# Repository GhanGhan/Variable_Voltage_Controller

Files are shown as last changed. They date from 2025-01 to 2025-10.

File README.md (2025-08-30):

# Overview
Desktop device that outputs a variable voltage whos value is controlled by the user.  The user will be able to monitor the input and output voltage and current.  This device will be suitable for prototyping, lab-bench testing and recreational purposes.
**The firmware for this projected is in the "Program" folder.**
Adjusted
## Notable Features!!!!!!
- Reverse voltage protection
- Power multiplexing between the input voltage terminal block and input voltage jack (explanation of circuit in section Schematic->Power->System Power Input)
  - **Allows user to hot-swap power sources while minimzing conduction losses!!!!**
- Real time voltage and current updates
Labelled

## PCB Notes
- 6-Layer stackup: Signal/GNDD/VCC/PGND/AGND/Signal
- Manufactured by JLCPCB
PCB View

# System Architecture
The system provides:
- A jack and terminal block for connecting to an external power supply with a range of 3-17V
- A screen to display the input voltage, input current, output voltage and output current in real time
- The ability to change the output voltage from 1.3V to 20V
- Terminal block connectors that allow an external load to connect to this device
Block Diagram

## System Description
An external power supply connects to the device via the input connectors.  The voltage is stepped down to 3.3V to power the display, microcontroller, and voltage controller.  A voltage and current sensor measures the external power supply’s voltage and current output and sends the readings to the microcontroller.  The user can operate the voltage controller to adjust the voltage sent to the output connector, which involves either a buck or boost conversion as the output voltage can range from 0 to 20V.  Another set of voltage and current sensors measures the voltage and current delivered to the load and sends those readings to the microcontroller.  The microcontroller processes the signals received from the sensors and sends the processed data to the display, allowing the user to view the voltage and current supplied by the external power supply as well as the voltage and current delivered to the load.

# Schematics
## Power 
Power

### System Power Input
- Power source connects to the device via a jack or a screw terminal block
- Systems needs at least 3V, and input voltage should not exceed 17V
-	Power Multiplexer circuit acts like an OR-GATE, automatically allows the higher input voltage to power the device
-	For more information about the circuit operation: [Basics of Ideal Diodes](https://www.ti.com/lit/an/slvae51a/slvae51a.pdf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)
-	Supplies power to the 3.3V buck converter and the buck-boost converter
### 3V3 Priority Power Multiplexing
-	Either the 3.3V buck converter or the 3.3V pin from the ST-Link programmer interface can be used to power the 3.3V circuitry
-	Priority is given to the buck converter
-	For more information about the circuit operation: [Basics of Power MUX](https://www.ti.com/lit/an/slvae51a/slvae51a.pdf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)
### Variable Power Output
-	Can deliver between 1.32V to 20V and up to 4A current
-	Maximum output power for each voltage given by: $P_O = \frac{5}{3}V_I + 10$
-	Potentiometer in the feedback circuitry allows the user to control the output voltage
### 3V LDO - Display Power
-	LDO used to power the LCD screen, as the nominal input voltage is 3V
### Power-On Indicator
- Indicates whether the system is receiving power

## Microcontroller
Microcontroller

-	Powered by 3.3V and uses a 16MHz clock
-	Can be programmed/debugged via the SWD interface
- Senses the input current and voltage as well as the output current and voltage via the ADC pins
- Communicates with the LCD display via the SPI interface

## Sensors
Sensors

### Current Sensors
- Composed of an 11 mΩ current-shunt resistor (shown in **Power Schematic**) and a difference amplifier with a 50V/V gain
- Senses uni-directional current up to 4A, scales output to 3.3V 
### Voltage Sensors
- Made using a voltage divider circuit
- Appropriately scaled so that the max voltage it experiences will output to 3.3V approximately

## Display
LCD

-	Powered by 3.0V
-	Has a backlight that is always on
-	Receives information about the system from the microcontroller via SPI 
- Display has a refresh rate of 10Hz

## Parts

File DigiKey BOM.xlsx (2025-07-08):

Reference | Value | Datasheet | Footprint | Qty | Manufacturer Part # | Cost | Total Cost
J102,J103 | Screw_Terminal_01x02 | ~ | TerminalBlock_Phoenix:TerminalBlock_Phoenix_MKDS-1,5-2_1x02_P5.00mm_Horizontal | 2 | 1984617 | $1.26 | $2.52
J201 | Conn_01x05 | ~ | Connector_PinHeader_2.54mm:PinHeader_1x05_P2.54mm_Vertical | 1 | PPTC051LFBN-RC | $0.62 | $0.62
RV101 | 1M ADJ | ~ | Potentiometer_THT:Potentiometer_Bourns_PTV09A-1_Single_Vertical | 1 | PTV09A-4025F-A105 | $1.31 | $1.31
U301 | NHD-C12832A1Z-FSW-FBW-3V3 |  | Display:NHD-C12832A1Z-FSRGB | 1 | NHD-C12832A1Z-FSW-FBW-3V3 | $20.04 | $20.04
C122,C123,C302,C303,C304,C305,C306 | 1uF | ~ | Capacitor_SMD:C_0402_1005Metric | 7 | CL05A105KP5NNNC | $0.15 | $1.05
D201,D202,D203,D204 | D_TVS | ~ | Diode_SMD:D_SOD-323 | 4 | PESD3V3L1BA,115 | $0.43 | $1.72
U104 | TPS62172DSG | http://www.ti.com/lit/ds/symlink/tps62170.pdf | Package_SON:WSON-8-1EP_2x2mm_P0.5mm_EP0.9x1.6mm_ThermalVias | 1 | TPS62172DSGR | $1.83 | $1.83
R101,R104,R105,R107,R108,R109,R110,R115 | 100k | ~ | Resistor_SMD:R_0402_1005Metric | 8 | RC0402FR-07100KL | $0.16 | $1.28
U106 | MCP1700T-3002E/TT | http://ww1.microchip.com/downloads/en/DeviceDoc/20001826D.pdf | Package_TO_SOT_SMD:SOT-23 | 1 | MCP1700T-3002E/TT | $0.80 | $0.80
C301,C307,C308 | 2.2uF | ~ | Capacitor_SMD:C_0402_1005Metric | 3 | GRM155R61E225ME15D | $0.28 | $0.84
C201 | 4.7uF | ~ | Capacitor_SMD:C_0402_1005Metric | 1 | GRM155R60J475KE96D |  | $0.00 | Not in Digikey
C121 | 10nF | ~ | Capacitor_SMD:C_0402_1005Metric | 1 | GRM155R71E103KA01D | $0.15 | $0.15
C101,C102,C111 | 22uF | ~ | Capacitor_SMD:C_1206_3216Metric | 3 | GRM31CR61E226KE15L |  | $0.00 | Obselete
U101 | MCP6541T-I/OT | http://ww1.microchip.com/downloads/en/DeviceDoc/MCP6561-1R-1U-2-4-1.8V-Low-Power-Push-Pull-Output-Comparator-DS20002139E.pdf | Package_TO_SOT_SMD:SOT-353_SC-70-5 | 1 | MCP6541T-I/OT | $0.61 | $0.61
C108,C109,C110,C112,C113,C115 | 10uF | ~ | Capacitor_SMD:C_0805_2012Metric | 6 | GRM21BR61E106KA73L | $0.35 | $2.10
R401 | 9.1k | ~ | Resistor_SMD:R_0603_1608Metric | 1 | RC0603FR-079K1L | $0.16 | $0.16
R402 | 2.2k | ~ | Resistor_SMD:R_0603_1608Metric | 1 | RC0603FR-072K2L | $0.16 | $0.16
D103,D104,D105 | BAT54WS-7-F | https://assets.nexperia.com/documents/data-sheet/BAT54J.pdf | Diode_SMD:D_SOD-323F | 3 | BAT54WS-7-F | $0.15 | $0.45
U401,U402 | INA213AIDCKR |  | Package_TO_SOT_SMD:SOT-363_SC-70-6 | 2 | INA213AIDCKR | $1.22 | $2.44
Q102,Q103 | IRFML8244TRPBF | https://ngspice.sourceforge.io/docs/ngspice-html-manual/manual.xhtml#cha_MOSFETs | Package_TO_SOT_SMD:SOT-23 | 2 | IRFML8244TRPBF | $0.56 | $1.12
C103,C104,C105,C106,C107,C114,C116,C117,C118,C202,C205,C401,C402 | 0.1uF | ~ | Capacitor_SMD:C_0402_1005Metric | 13 | CL05B104KA5NNNC | $0.12 | $1.56
C120 | 100uF | ~ | Capacitor_SMD:CP_Elec_6.3x7.7 | 1 | EEEFTH101XAP | $1.37 | $1.37
R102,R103 | 50k | ~ | Resistor_SMD:R_0402_1005Metric | 2 | RTT025002FTH |  | $0.00
R114 | 140k | ~ | Resistor_SMD:R_0603_1608Metric | 1 | RC0603FR-07140KL | $0.16 | $0.16
C119 | 240pF | ~ | Capacitor_SMD:C_0603_1608Metric | 1 | GRM1885C1H241JA01D | $0.21 | $0.21
Y201 | 16MHz | ~ | Crystal:Crystal_SMD_3225-4Pin_3.2x2.5mm | 1 | 7U16000E12UCG |  | $0.00
Q104,Q105,Q106,Q107 | AO3407 | http://www.aosmd.com/pdfs/datasheet/AO3401A.pdf | Package_TO_SOT_SMD:SOT-23 | 4 | AO3407 |  | $0.00
R404 | 4.7K | ~ | Resistor_SMD:R_0402_1005Metric | 1 | ERJ2RKF4701X | $0.16 | $0.16
L101,L102 | 2.2uH | ~ | Inductor_SMD:L_Sunlord_MWSA0503S | 2 | MWSA0503S-2R2MT | $1.21 | $2.42
R403 | 24K | ~ | Resistor_SMD:R_0402_1005Metric | 1 | ERJ2RKF2402X | $0.16 | $0.16
R113 | 160R | ~ | Resistor_SMD:R_0603_1608Metric | 1 | ERJ2RKF1600X | $0.16 | $0.16
R106,R116 | 11mR | ~ | Resistor_SMD:R_1210_3225Metric | 2 | 1210W2F110MT5E |  | $0.00
C203,C204 | 14pF | ~ | Capacitor_SMD:C_0402_1005Metric | 2 | 0402N140J500CT |  | $0.00
Q101,Q108,Q109,Q110 | AO3416 | http://www.aosmd.com/pdfs/datasheet/AO3400A.pdf | Package_TO_SOT_SMD:SOT-23 | 4 | AO3416 | $0.74 | $2.96
D101,D102 | D_TVS | ~ | Diode_SMD:D_SOD-882 | 2 | PESD18VF1BLYL | $0.25 | $0.50
U201 | STM32G030F6Px | https://www.st.com/resource/en/datasheet/stm32g030f6.pdf | Package_SO:TSSOP-20_4.4x6.5mm_P0.65mm | 1 | STM32G030F6P6 | $2.02 | $2.02
R112 | 4.3k | ~ | Resistor_SMD:R_0805_2012Metric | 1 | RT0805BRD074K3L | $0.25 | $0.25
R111 | 5k | ~ | Resistor_SMD:R_0603_1608Metric | 1 | RT0603BRE075KL | $0.27 | $0.27
SW201 | SW_Push | ~ | Button_Switch_SMD:SW_Tactile_SPST_NO_Straight_CK_PTS636Sx25SMTRLFS | 1 | PTS636SK25SMTRLFS | $0.34 | $0.34
J101 | Jack-DC | ~ | Connector_BarrelJack:BarrelJack_CUI_PJ-063AH_Horizontal | 1 | PJ-063AH |  | $0.00
U102,U103 | LM74700 | http://www.ti.com/lit/gpn/LM74700-Q1 | Package_TO_SOT_SMD:SOT-23-6 | 2 | LM74700QDBVRQ1 | $2.62 | $5.24
R117 | 6.4k | ~ | Resistor_SMD:R_0603_1608Metric | 1 | ARG03DTC6401N |  | $0.00
D106 | Green LED | ~ | LED_SMD:LED_0603_1608Metric | 1 | 150060GS75000 | $0.24 | $0.24
U105 | TPS552872RYQR |  | Buck_Boost:21-PowerVFQFN | 1 | TPS552872RYQR | $6.63 | $6.63
Total |  |  |  | 98 |  |  | $63.85

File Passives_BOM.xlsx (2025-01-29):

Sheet: Capacitors
Capacitance (uF) | Name | Tolerance % | Voltage Rating (V) | Size | Caps
1uF | CL05A105KP5NNNC (https://jlcpcb.com/partdetail/15107-CL05A105KP5NNNC/C14445) | 10 | 10 | 0402 | C122, C123, C302-C306
22uF | GRM31CR61E226KE15L (https://jlcpcb.com/partdetail/MurataElectronics-GRM31CR61E226KE15L/C77091) | 10 | 25 | 1206 | C101, C102, C111
0.1uF | CL05B104KA5NNNC (https://jlcpcb.com/partdetail/166764-CL05B104KA5NNNC/C155422) | 10 | 25 | 0402 | C103-C107, C114, C116, C117, C118, C202, C205, C401, C402
10uF | GRM21BR61E106KA73L (https://jlcpcb.com/partdetail/MurataElectronics-GRM21BR61E106KA73L/C84416) | 10 | 25 | 0805 | C108, C109, C110, C112, C113, C115
2.2uF | GRM155R61E225ME15D (https://jlcpcb.com/partdetail/MurataElectronics-GRM155R61E225ME15D/C72203) | 20 | 25 | 0402 | C301, C307, C308
14pF | 0402N140J500CT (https://jlcpcb.com/partdetail/Walsin_TechCorp-0402N140J500CT/C458857) | 5 | 50 | 0402 | C203, C204
240pF | GRM1885C1H241JA01D (https://jlcpcb.com/partdetail/196998-GRM1885C1H241JA01D/C185593) | 5 | 50 | 0603 | C119
100uF | EEEFTH101XAP (https://jlcpcb.com/partdetail/Panasonic-EEEFTH101XAP/C165974) | 20 | 50 | D6.3xL7.7mm | C120
10nF | GRM155R71E103KA01D (https://jlcpcb.com/partdetail/MurataElectronics-GRM155R71E103KA01D/C77013) | 10 | 25 | 0402 | C121
4.7uF | GRM155R60J475KE96D (https://jlcpcb.com/partdetail/MurataElectronics-GRM155R60J475KE96D/C76995) | 10 | 6.3 | 0402 | C201

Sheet: Inductor
Inductance | Name | Tolerance % | Saturation Current (A) | Size | Inductors
2.2uH | MWSA0503S-2R2MT | 20% | 7.2 | 5.4x5.2x2.8mm | L101, L102

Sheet: Resistors
Resistance | Name | Tolerance % | Power | Size | Resistors
100kohm | RC0402FR-07100KL (https://jlcpcb.com/partdetail/Yageo-RC0402FR07100KL/C60491) | 1 | 62.5mW | 0402 | R101, R104, R105, R107-R110, R115
50kohm | RTT025002FTH (https://jlcpcb.com/partdetail/Ralec-RTT025002FTH/C166559) | 1 | 62.5mW | 0402 | R102, R103
11mohm | 1210W2F110MT5E (https://jlcpcb.com/partdetail/415373-1210W2F110MT5E/C422423) | 1 | 500mW | 1210 | R106, R116
5kohm | RT0603BRE075KL (https://jlcpcb.com/partdetail/Yageo-RT0603BRE075KL/C862232) | 0.1 | 100mW | 0603 | R111
4.3kohm | RT0805BRD074K3L (https://jlcpcb.com/partdetail/Yageo-RT0805BRD074K3L/C728653) | 0.1 | 125mW | 0805 | R112
160ohm | ERJ2RKF1600X (https://jlcpcb.com/partdetail/Panasonic-ERJ2RKF1600X/C413068) | 1 | 100mW | 0402 | R113
140kohm | RC0603FR-07140KL (https://jlcpcb.com/partdetail/Yageo-RC0603FR07140KL/C185372) | 1 | 100mW | 0603 | R114
6.4kohm | ARG03DTC6401N (https://jlcpcb.com/partdetail/VikingTech-ARG03DTC6401N/C3014413) | 0.5 | 100mW | 0603 | R117
9.1kohm | RC0603FR-079K1L (https://jlcpcb.com/partdetail/Yageo-RC0603FR079K1L/C114639) | 1 | 100mW | 0603 | R401
2.2kohm | RC0603FR-072K2L (https://jlcpcb.com/partdetail/Yageo-RC0603FR072K2L/C114662) | 1 | 100mW | 0603 | R402
24kohm | ERJ2RKF2402X (https://jlcpcb.com/partdetail/Panasonic-ERJ2RKF2402X/C409902) | 1 | 100mW | 0402 | R403
4.7kohm | ERJ2RKF4701X (https://jlcpcb.com/partdetail/Panasonic-ERJ2RKF4701X/C400631) | 1 | 100mW | 0402 | R404

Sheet: Potentiometer
Resistance | Name | Tolerance % | Power | Size | Resistors
1Mohm | PTV09A-4025F-A105 (https://www.digikey.ca/en/products/detail/bourns-inc/PTV09A-4025F-A105/3820576) | 20 | 50mW | Through Hole, Snap In | Rv101

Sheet: Switch
Name | Size | Switch
PTS636SK25SMTRLFS (https://jlcpcb.com/partdetail/ck-PTS636SK25SMTRLFS/C2689642) | 6x3.5 | SW201

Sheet: Connectors
Connector | Name | Voltage Rating | Current Rating | Size (pitch) | Annotation
Input Voltage Jack | PJ-063AH (https://www.digikey.ca/en/products/detail/same-sky-formerly-cui-devices/PJ-063AH/2161208) | 24V | 8A | 5.5mm | J101
Input Voltage Block | 1984617 (https://www.digikey.ca/en/products/detail/phoenix-contact/1984617/950849) | 300V | 10A | 3.5mm | J102
Output Voltage Block | 1984617 (https://www.digikey.ca/en/products/detail/phoenix-contact/1984617/950849) | 300V | 10A | 3.5mm | J103
ST-Link Header | PPTC051LFBN-RC (https://www.digikey.ca/en/products/detail/sullins-connector-solutions/PPTC051LFBN-RC/807239) | 250V | 3A | 2.54mm | J201

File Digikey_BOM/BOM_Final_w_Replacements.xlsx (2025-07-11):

Index | Quantity | Part Number | Manufacturer Part Number | Description | Customer Reference | Available | Backorder | Unit Price | Extended Price USD
1 | 1 | CP-063AH-ND | PJ-063AH | CONN PWR JACK 2X5.5MM SOLDER | J101 | 1 | 0 | 1.5 | 1.50
2 | 2 | 277-1721-ND | 1984617 | TERM BLK 2POS SIDE ENT 3.5MM PCB | J102,J103 | 2 | 0 | 0.86 | 1.72
3 | 1 | S6103-ND | PPTC051LFBN-RC | CONN HDR 5POS 0.1 TIN PCB | J201 | 1 | 0 | 0.38 | 0.38
4 | 1 | 118-PTV09A-4025F-A105-ND | PTV09A-4025F-A105 | POT 1M OHM 1/20W CARBON LOG | RV101 | 1 | 0 | 0.89 | 0.89
5 | 1 | NHD-C12832A1Z-FSW-FBW-3V3-ND | NHD-C12832A1Z-FSW-FBW-3V3 | GRAPHIC DISPLAY FSTN BLACK (WHIT | U301 | 1 | 0 | 12.78 | 12.78
6 | 13 | 1276-6720-1-ND | CL05B104KA5NNNC | CAP CER 0.1UF 25V X7R 0402 | C103,C104,C105,C106,C107,C114,C116,C117,C118,C20 | 13 | 0 | 0.008 | 0.10
7 | 1 | 490-1436-1-ND | GRM1885C1H241JA01D | CAP CER 240PF 50V C0G/NP0 0603 | C119 | 1 | 0 | 0.14 | 0.14
8 | 1 | PCE5024CT-ND | EEE-FTH101XAP | CAP ALUM 100UF 20% 50V SMD | C120 | 1 | 0 | 0.93 | 0.93
9 | 3 | BAT54WS-FDICT-ND | BAT54WS-7-F | DIODE SCHOTTKY 30V 100MA SOD323 | D103,D104,D105 | 3 | 0 | 0.1 | 0.30
10 | 2 | 490-GCM1555C1H110FA16DCT-ND | GCM1555C1H110FA16D | CAP CER 11PF 50V C0G/NP0 0402 | C203,C204 | 2 | 0 | 0.1 | 0.20
11 | 1 | 732-4971-1-ND | 150060GS75000 | LED GREEN CLEAR 0603 SMD | D106 | 1 | 0 | 0.15 | 0.15
12 | 1 | P160LCT-ND | ERJ-2RKF1600X | RES SMD 160 OHM 1% 1/10W 0402 | R113 | 1 | 0 | 0.1 | 0.10
13 | 1 | P24.0KLCT-ND | ERJ-2RKF2402X | RES SMD 24K OHM 1% 1/10W 0402 | R403 | 1 | 0 | 0.1 | 0.10
14 | 1 | MCP6541T-I/OTCT-ND | MCP6541T-I/OT | IC COMPARATOR 1 GEN PUR SOT23-5 | U101 | 1 | 0 | 0.39 | 0.39
15 | 1 | MCP1700T-3002E/TTCT-ND | MCP1700T-3002E/TT | IC REG LINEAR 3V 250MA SOT23-3 | U106 | 1 | 0 | 0.51 | 0.51
16 | 2 | 296-53420-1-ND | LM74700QDBVTQ1 | LOW IQ, IDEAL DIODE CONTROLLER | U102,U103 | 2 | 0 | 2.07 | 4.14
17 | 1 | 311-140KHRCT-ND | RC0603FR-07140KL | RES 140K OHM 1% 1/10W 0603 | R114 | 1 | 0 | 0.1 | 0.10
18 | 2 | 1727-1480-1-ND | PESD18VF1BLYL | TVS DIODE 18VWM 17VC DFN1006-2 | D101,D102 | 2 | 0 | 0.17 | 0.34
19 | 4 | 1727-3825-1-ND | PESD3V3L1BA,115 | TVS DIODE 3.3VWM 26VC SOD323 | D201,D202,D203,D204 | 4 | 0 | 0.29 | 1.16
20 | 4 | 785-1011-1-ND | AO3416 | MOSFET N-CH 20V 6.5A SOT23-3L | Q101,Q108,Q109,Q110 | 4 | 0 | 0.5 | 2.00
21 | 2 | IRFML8244TRPBFCT-ND | IRFML8244TRPBF | MOSFET N-CH 25V 5.8A SOT23 | Q102,Q103 | 2 | 0 | 0.36 | 0.72
22 | 1 | CKN12324-1-ND | PTS636SKG25SMTR LFS | SWITCH TACTILE SPST-NO 0.05A 12V | SW201 | 1 | 0 | 0.24 | 0.24
23 | 2 | 296-26072-1-ND | INA213AIDCKR | IC CURR SENSE 1 CIRCUIT SC70-6 | U401,U402 | 2 | 0 | 0.77 | 1.54
24 | 4 | 785-AOSS21311CCT-ND | AOSS21311C | MOSFET P-CH 30V 4.3A SOT23-3 | Q104,Q105,Q106,Q107 | 4 | 0 | 0.46 | 1.84
25 | 2 | 541-CRCW040250K0FKEDCT-ND | CRCW040250K0FKED | D10/CRCW0402 100 50K 1% ET7 E3 | R102,R103 | 2 | 0 | 0.1 | 0.20
26 | 2 | 1712-RLC73PV2ER011FTDCT-ND | RLC73PV2ER011FTD | RLC73PV 2E R011 1% 5K RL | R106,R116 | 2 | 0 | 0.84 | 1.68
27 | 1 | RMCF0805FT4K30CT-ND | RMCF0805FT4K30 | RES 4.3K OHM 1% 1/8W 0805 | R112 | 1 | 0 | 0.1 | 0.10
28 | 1 | 2019-RN73R1JTTD6421B25CT-ND | RN73R1JTTD6421B25 | RES 6.42K OHM 0.1% 1/10W 0603 | R117 | 1 | 0 | 0.12 | 0.12
29 | 1 | 2019-RK73H1ERTTP4751FCT-ND | RK73H1ERTTP4751F | RES 4.75K OHM 1% 1/10W 0402 | R404 | 1 | 0 | 0.13 | 0.13
30 | 1 | 541-MCT06030D5001BP500CT-ND | MCT06030D5001BP500 | RES 5K OHM 0.1% 1/10W 0603 | R111 | 1 | 0 | 0.19 | 0.19

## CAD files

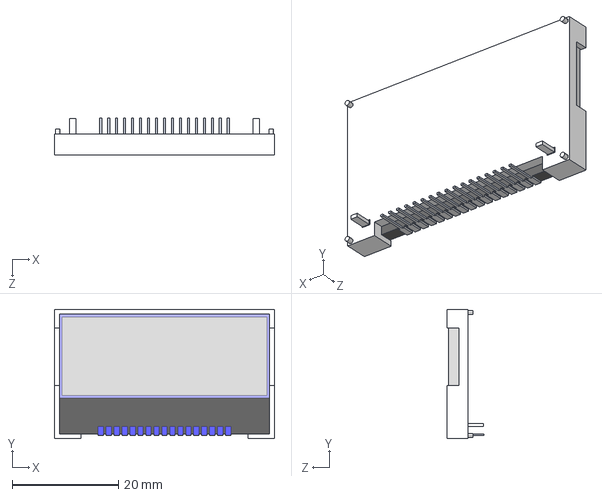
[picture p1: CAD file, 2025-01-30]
Var_Volt_Conv/Project_Library/3d_Models/NHD-C12832A1Z.STEP
41.4 x 24.3 x 7.00 mm

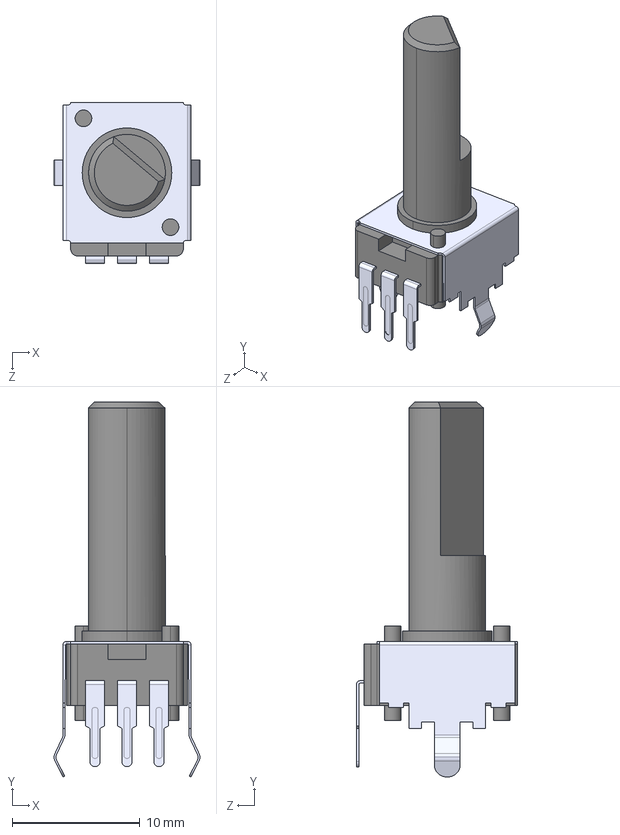
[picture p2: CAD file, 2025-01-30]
Var_Volt_Conv/Project_Library/3d_Models/PTV09A-4225F-B104.step
11.4 x 29.3 x 12.6 mm

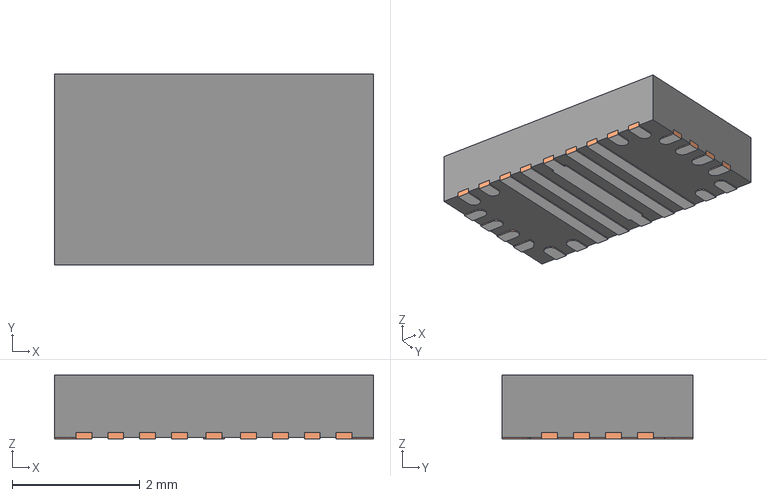
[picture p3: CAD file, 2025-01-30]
Var_Volt_Conv/Project_Library/3d_Models/RYQ0021A.stp
5.00 x 3.00 x 1.00 mm
BODY-QFN
FRAME-RYQ0021A

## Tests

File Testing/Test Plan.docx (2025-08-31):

# Variable Voltage Controller Test Plan

# Tools Required

- Benchtop power supply that can output up to 17V and 5A
- Digital multimeter that can perform continuity checks and measure up to 20V
- A variable power supply that can connect to a DC power jack
- The STM32CubeIDE that can run the program on the microcontroller in Debug Mode
- Digital oscilloscope
- Variable resistor and or rheostat

# Bring-Up

## Visual Inspection & Continuity Check

- Ensure all components are soldered onto the board and in the correct orientation
- Verify that there are no shorts between the power traces (Vin, Vo, 3.3V, 3.0V) and ground

## Power On

- Ensure that the output voltage terminal is in an open-circuit state
- Connect terminal block to bench-top power supply
- Turn bench top power supply on and slowly increase the voltage to 5V
- Check that the power indicator LED is on and that none of the components are heating up
- Use multimeter to check that all non-varying power rails (Vin, 3.3V and 3.0V) are at the correct value
- Increase input voltage from 5V to 17V (maximum input voltage for the device), recheck that none of the components overheating and that all the non-varying power rails are still set to the correct voltage level
- Connect a multimeter to the output terminal
- Rotate the potentiometer from it’s lowest setting to it’s highest setting, check that the output voltage increases from 1.32V to 20V

## Firmware Validation

- Connect device to a computer via the SWD interface, check that the computer can identify the microcontroller
- Upload a program that allows the microcontroller to transmit data to the LCD screen via the SPI interface, check that the message is correct
- Write and upload a program that the device will use during normal operation

# Functional Testing

## System Input Voltage Multiplexer Test

- Purpose: To confirm that the power multiplexer allows for two voltage sources to connect to the PCB at the same time, and the source with the larger voltage will deliver power to the device
- Procedure:
  - Ensure no load is connected to the output voltage terminals
  - Connect a variable power source to the DC power jack
  - Connect the bench-top supply source to the terminal block
  - A) Set the power jack source to 9V, vary the terminal block source from 3V to 17V
  - B) Set the terminal block source to 9V, vary the jack source from 3V to 17V
- Expected Result:
  - The power indicator LED and LCD screen should be turned on for the duration of the test
  - A – while the jack source is set to 9V, the LCD screen should display an input voltage of 9V until the benchtop supply > 9V, after which the measured input voltage should equal the benchtop supply source
  - B – while the terminal source is set to 9V, the LCD screen should display an input voltage of 9V until the jack source is > 9V, after which the measured input voltage should equal the jack supply source

## DC-DC Conversion Test

- Purpose: To confirm that the input voltage is accurately sensed by the input voltage sensor and that the value is displayed on the LCD screen error free
- Procedure:
  - Ensure no load is connected to the output voltage terminal
  - Connect the benchtop power supply to the input terminal block
  - Connect the oscilloscope probes to the input and output terminal blocks
  - Connect the programmer to the board, and operate the device in debug mode
    - Place a breakpoint after all the electrical value print statements
  - Change output voltage to Vo = {1.32V, 4V, 10V, 20V}
    - Change input voltage Vi = {3V, 6V, 12V, 17V
      - Set resistor value so that output current will be 4mA, 400mA, 1.5A and 4A/Max value
      - Record Vo, Vi, Io and Ii
      - Record oscilloscope waveform of Vo and Vi
      - ***If output value is ‘unstable’, make note of it
- Expected Result
  - Electrical values are stable under various loads
  - Power output limited by P = 1.667V + 10

## 3.3V Priority Multiplexer Test

- Purpose: To confirm that the programming header supplies the 3.3V circuitry with power if no supply is connected to the input terminals, otherwise the buck converter supplies the PCB with 3.3V
- Procedure:
  - Connect the benchtop power supply to the input terminal block and turn it on
  - Connect the programming header to the PCB and the laptop
  - Turn the power supply off, check the power indicator light of the PCB
  - Disconnect both the programming header and the power supply, then reconnect both and turn on the power supply
  - Unplug the programming header, check the power indicator light of the PCB
- Expected Result:
  - If both the header and benchtop supply are connected at the same time, the power indicator light should remain on if either of them are unplugged

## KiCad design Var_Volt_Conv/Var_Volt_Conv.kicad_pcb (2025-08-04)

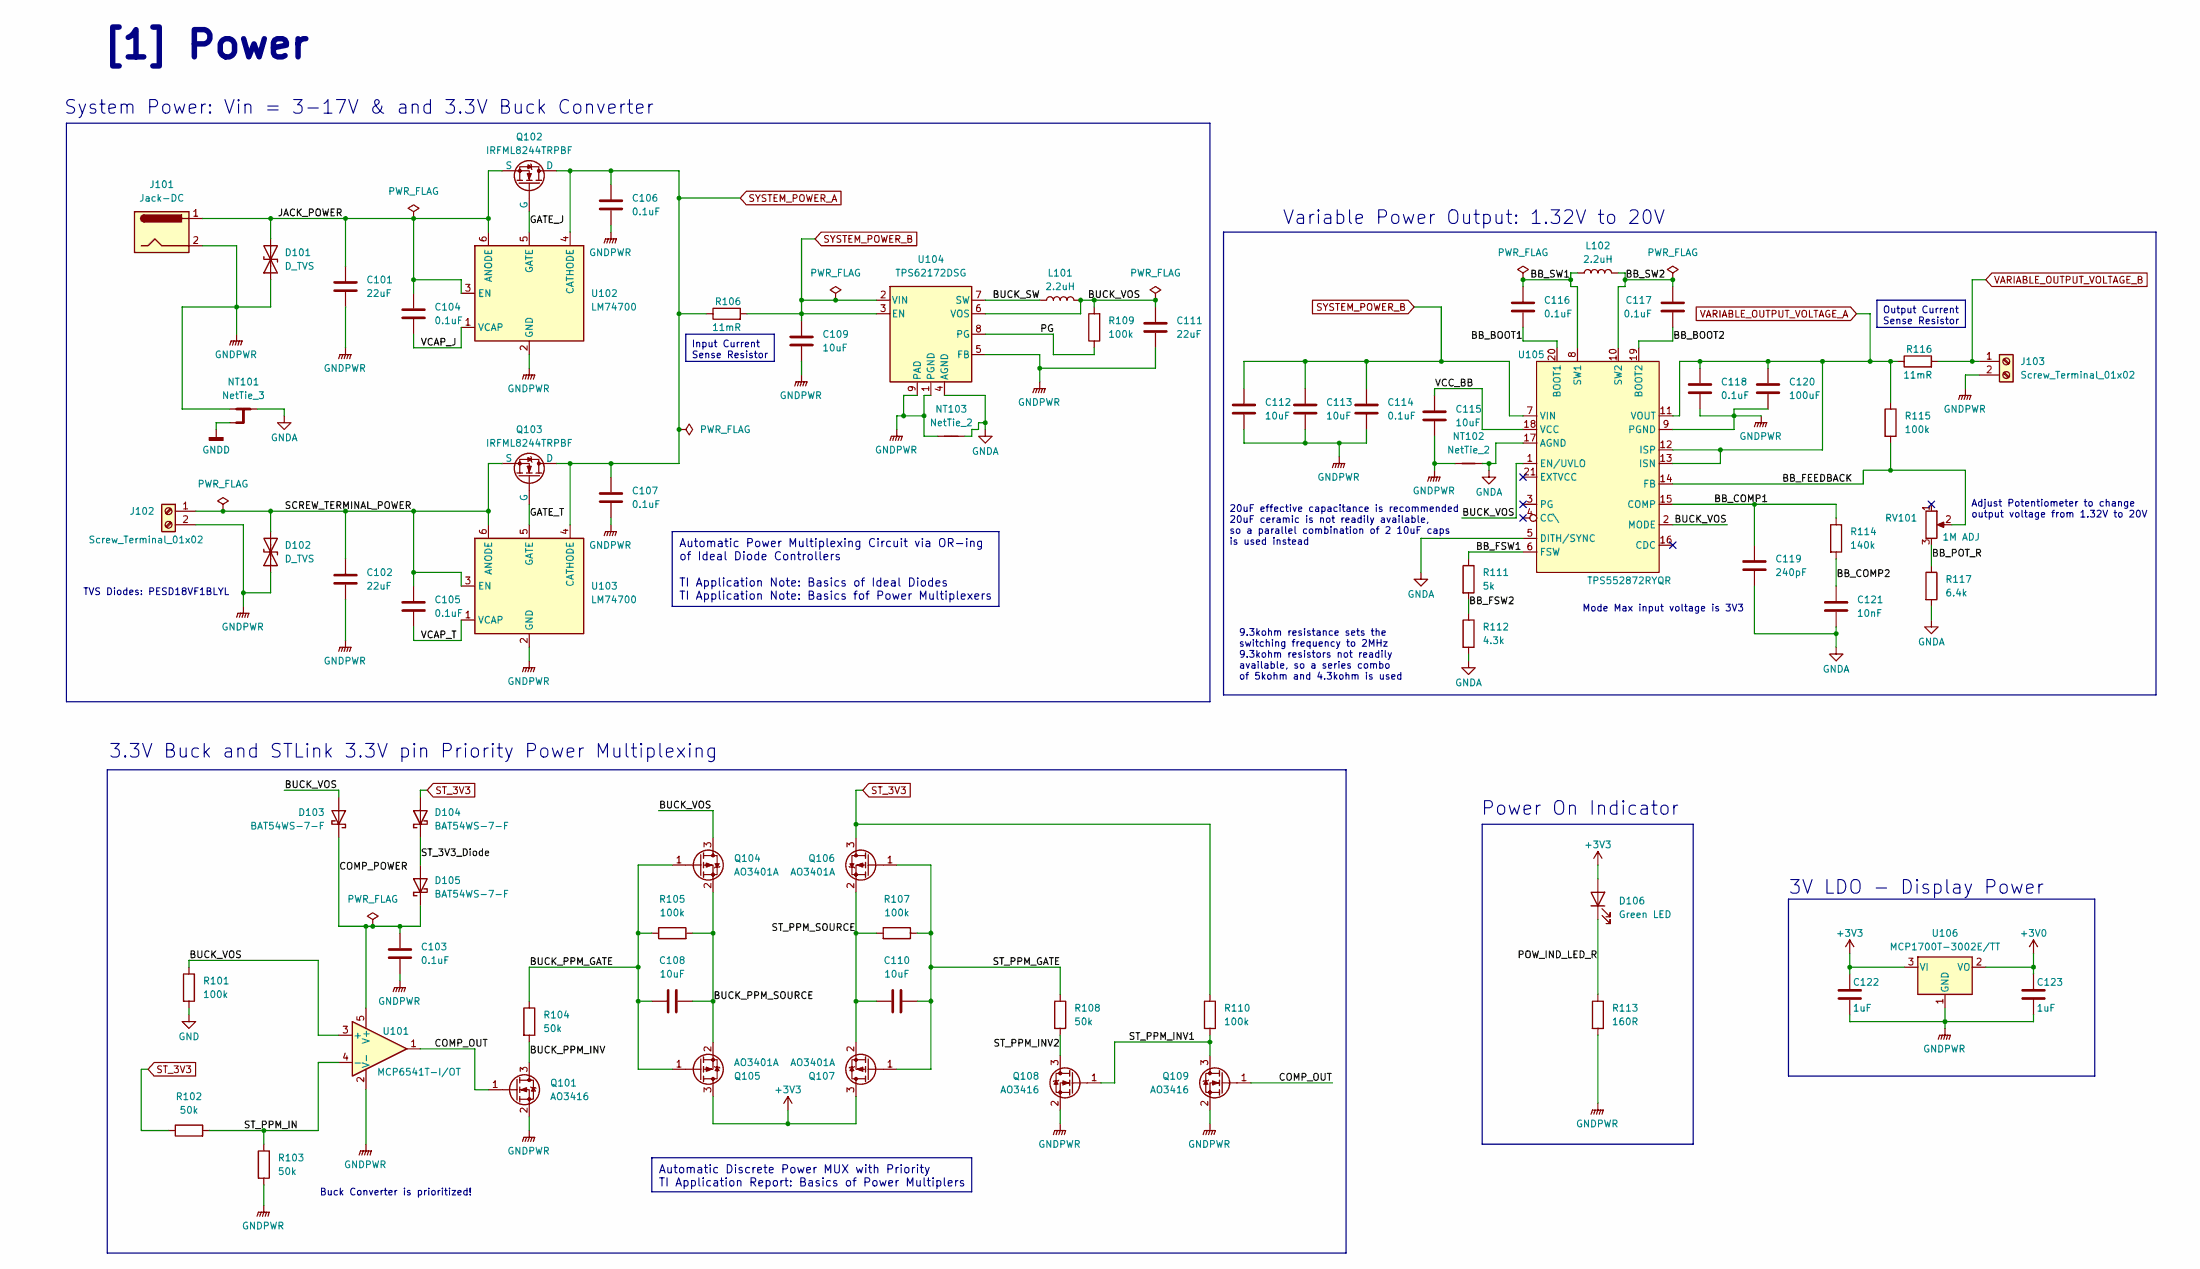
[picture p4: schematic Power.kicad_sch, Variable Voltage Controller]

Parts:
C101, C102, C111: 22uF; C_1206_3216Metric; Manufacturer Part # CL31A226KAHNNNE; lcsc C12891
C103, C104, C105, C106, C107, C114, C116, C117, C118: 0.1uF; C_0402_1005Metric; Manufacturer Part # CL05B104KA5NNNC; lcsc C155422
C108, C109, C110, C112, C113, C115: 10uF; C_0805_2012Metric; Manufacturer Part # CL21A106KAYNNNE; lcsc C15850
C119: 240pF; C_0603_1608Metric; Manufacturer Part # GRM1885C1H241JA01D; lcsc C185593
C120: 100uF; CP_Elec_6.3x7.7; Manufacturer Part # EEEFTH101XAP; lcsc C165974
C121: 10nF; C_0402_1005Metric; Manufacturer Part # CL05B103KB5NNNC; lcsc C15195
C122, C123: 1uF; C_0402_1005Metric; Manufacturer Part # CL05A105KA5NQNC; lcsc C52923
D101, D102: D_TVS; D_SOD-882; Manufacturer Part # PESD18VF1BLYL; lcsc C686660
D103, D104, D105: BAT54WS-7-F; D_SOD-323F; Manufacturer Part # BAT54WS-7-F; lcsc C124205
D106: Green LED; LED_0603_1608Metric; Manufacturer Part # 150060GS75000; lcsc C5252984
J101: Jack-DC; BarrelJack_CUI_PJ-063AH_Horizontal; Manufacturer Part # PJ-063AH; lcsc C2928097
J102, J103: Screw_Terminal_01x02; TerminalBlock_Phoenix_MKDS-1,5-2_1x02_P5.00mm_Horizontal; Manufacturer Part # 1984617
L101, L102: 2.2uH; L_Sunlord_MWSA0503S; Manufacturer Part # MWSA0503S-2R2MT; lcsc C408408
NT101: NetTie_3; NetTie-3_THT_Pad1.0mm
NT102, NT103: NetTie_2; NetTie-2_SMD_Pad0.5mm
Q101, Q108, Q109: AO3416; SOT-23; Manufacturer Part # AO3416; lcsc C479060
Q102, Q103: IRFML8244TRPBF; SOT-23; Manufacturer Part # IRFML8244TRPBF; lcsc C143945
Q104, Q105, Q106, Q107: AO3401A; SOT-23; Manufacturer Part # AO3401A; lcsc C15127
R101, R105, R107, R109, R110, R115: 100k; R_0402_1005Metric; Manufacturer Part # 0402WGF1003TCE; lcsc C25741
R102, R103, R104, R108: 50k; R_0402_1005Metric; Manufacturer Part # RTT025002FTH; lcsc C166559
R106, R116: 11mR; R_1210_3225Metric; Manufacturer Part # 1210W2F110MT5E; lcsc C422423
R111: 5k; R_0603_1608Metric; Manufacturer Part # RT0603BRE075KL; lcsc C862232
R112: 4.3k; R_0805_2012Metric; Manufacturer Part # 0805W8F4301T5E; lcsc C17667
R113: 160R; R_0603_1608Metric; Manufacturer Part # ERJ2RKF1600X; lcsc C413068
R114: 140k; R_0603_1608Metric; Manufacturer Part # RC0603FR-07140KL; lcsc C185372
R117: 6.4k; R_0603_1608Metric; Manufacturer Part # ARG03DTC6401N; lcsc C3014413
RV101: 1M ADJ; Potentiometer_Bourns_PTV09A-1_Single_Vertical; Manufacturer Part # PTV09A-4025F-A105
U101: MCP6541T-I/OT; SOT-353_SC-70-5; Manufacturer Part # MCP6541T-I/OT; lcsc C80839
U102, U103: LM74700; SOT-23-6; Manufacturer Part # LM74700QDBVRQ1; lcsc C2941042
U104: TPS62172DSG; WSON-8-1EP_2x2mm_P0.5mm_EP0.9x1.6mm_ThermalVias; Manufacturer Part # TPS62172DSGR; lcsc C59873
U105: TPS552872RYQR; 21-PowerVFQFN; Manufacturer Part # TPS552872RYQR; lcsc C22427496
U106: MCP1700T-3002E/TT; SOT-23; Manufacturer Part # MCP1700T-3002E/TT; lcsc C62244

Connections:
+3V0: C123.1, U106.2 (VO); also elsewhere on the board
+3V3: C122.1, D106.2 (A), Q105.3 (D), Q107.3 (D), U106.3 (VI); also elsewhere on the board
/[1] Power/BB_BOOT1: C116.2, U105.20 (BOOT1)
/[1] Power/BB_BOOT2: C117.2, U105.19 (BOOT2)
/[1] Power/BB_COMP1: C119.1, R114.1, U105.15 (COMP)
/[1] Power/BB_COMP2: C121.1, R114.2
/[1] Power/BB_FEEDBACK: R115.2, RV101.2, U105.14 (FB)
/[1] Power/BB_FSW1: R111.1, U105.6 (FSW)
/[1] Power/BB_FSW2: R111.2, R112.1
/[1] Power/BB_POT_R: R117.1, RV101.3
/[1] Power/BB_SW1: C116.1, L102.1, U105.8 (SW1)
/[1] Power/BB_SW2: C117.1, L102.2, U105.10 (SW2)
/[1] Power/BUCK_PPM_GATE: C108.1, Q104.1 (G), Q105.1 (G), R104.1, R105.1
/[1] Power/BUCK_PPM_INV: Q101.3 (D), R104.2
/[1] Power/BUCK_PPM_SOURCE: C108.2, Q104.2 (S), Q105.2 (S), R105.2
/[1] Power/BUCK_SW: L101.1, U104.7 (SW)
/[1] Power/BUCK_VOS: C111.1, D103.2 (A), L101.2, Q104.3 (D), R101.1, R109.2, U101.3 (+), U104.6 (VOS), U105.1 (EN/UVLO), U105.2 (MODE)
/[1] Power/COMP_OUT: Q101.1 (G), Q109.1 (G), U101.1
/[1] Power/COMP_POWER: C103.1, D103.1 (K), D105.1 (K), U101.5 (V+)
/[1] Power/GATE_J: Q102.1 (G), U102.5 (GATE)
/[1] Power/GATE_T: Q103.1 (G), U103.5 (GATE)
/[1] Power/JACK_POWER: C101.1, C104.1, D101.2 (A2), J101.1, Q102.2 (S), U102.3 (EN), U102.6 (ANODE)
/[1] Power/PG: R109.1, U104.8 (PG)
/[1] Power/POW_IND_LED_R: D106.1 (K), R113.1
/[1] Power/SCREW_TERMINAL_POWER: C102.1, C105.1, D102.2 (A2), J102.1, Q103.2 (S), U103.3 (EN), U103.6 (ANODE)
/[1] Power/ST_3V3_Diode: D104.1 (K), D105.2 (A)
/[1] Power/ST_PPM_GATE: C110.1, Q106.1 (G), Q107.1 (G), R107.1, R108.1
/[1] Power/ST_PPM_IN: R102.2, R103.1, U101.4 (-)
/[1] Power/ST_PPM_INV1: Q108.1 (G), Q109.3 (D), R110.2
/[1] Power/ST_PPM_INV2: Q108.3 (D), R108.2
/[1] Power/ST_PPM_SOURCE: C110.2, Q106.2 (S), Q107.2 (S), R107.2
/[1] Power/VCAP_J: C104.2, U102.1 (VCAP)
/[1] Power/VCAP_T: C105.2, U103.1 (VCAP)
/[1] Power/VCC_BB: C115.1, U105.18 (VCC)
GND: R101.2
GNDA: C119.2, C121.2, NT101.2, NT102.2, NT103.2, R112.2, R117.2, U104.4 (AGND), U105.5 (DITH/SYNC), U105.17 (AGND); also elsewhere on the board
GNDD: NT101.3; also elsewhere on the board
GNDPWR: C101.2, C102.2, C103.2, C106.2, C107.2, C109.2, C111.2, C112.2, C113.2, C114.2, C115.2, C118.2, C120.2, C122.2, C123.2, D101.1 (A1), D102.1 (A1), J101.2, J102.2, J103.2, NT101.1, NT102.1, NT103.1, Q101.2 (S), Q108.2 (S), Q109.2 (S), R103.2, R113.2, U101.2 (V-), U102.2 (GND), U103.2 (GND), U104.1 (PGND), U104.5 (FB), U104.9 (PAD), U105.9 (PGND), U106.1 (GND); also elsewhere on the board
ST_3V3: D104.2 (A), Q106.3 (D), R102.1, R110.1; also elsewhere on the board
SYSTEM_POWER_A: C106.1, C107.1, Q102.3 (D), Q103.3 (D), R106.1, U102.4 (CATHODE), U103.4 (CATHODE); also elsewhere on the board
SYSTEM_POWER_B: C109.1, C112.1, C113.1, C114.1, R106.2, U104.2 (VIN), U104.3 (EN), U105.7 (VIN); also elsewhere on the board
VARIABLE_OUTPUT_VOLTAGE_A: C118.1, C120.1, R115.1, R116.1, U105.11 (VOUT), U105.12 (ISP), U105.13 (ISN); also elsewhere on the board
VARIABLE_OUTPUT_VOLTAGE_B: J103.1, R116.2; also elsewhere on the board

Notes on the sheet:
Automatic Discrete Power MUX with Priority TI Application Report: Basics of Power Multiplers
Input Current Sense Resistor
Output Current Sense Resistor
Automatic Power Multiplexing Circuit via OR-ing of Ideal Diode Controllers TI Application Note: Basics of Ideal Diodes TI Application Note: Basics fof Power Multiplexers
9.3kohm resistance sets the switching frequency to 2MHz 9.3kohm resistors not readily available, so a series combo of 5kohm and 4.3kohm is used
System Power: Vin = 3-17V & and 3.3V Buck Converter
Variable Power Output: 1.32V to 20V
TVS Diodes: PESD18VF1BLYL
3V LDO - Display Power
Buck Converter is prioritized!
Mode Max input voltage is 3V3
[1] Power
Power On Indicator
20uF effective capacitance is recommended 20uF ceramic is not readily available, so a parallel combination of 2 10uF caps is used instead
Adjust Potentiometer to change output voltage from 1.32V to 20V
3.3V Buck and STLink 3.3V pin Priority Power Multiplexing

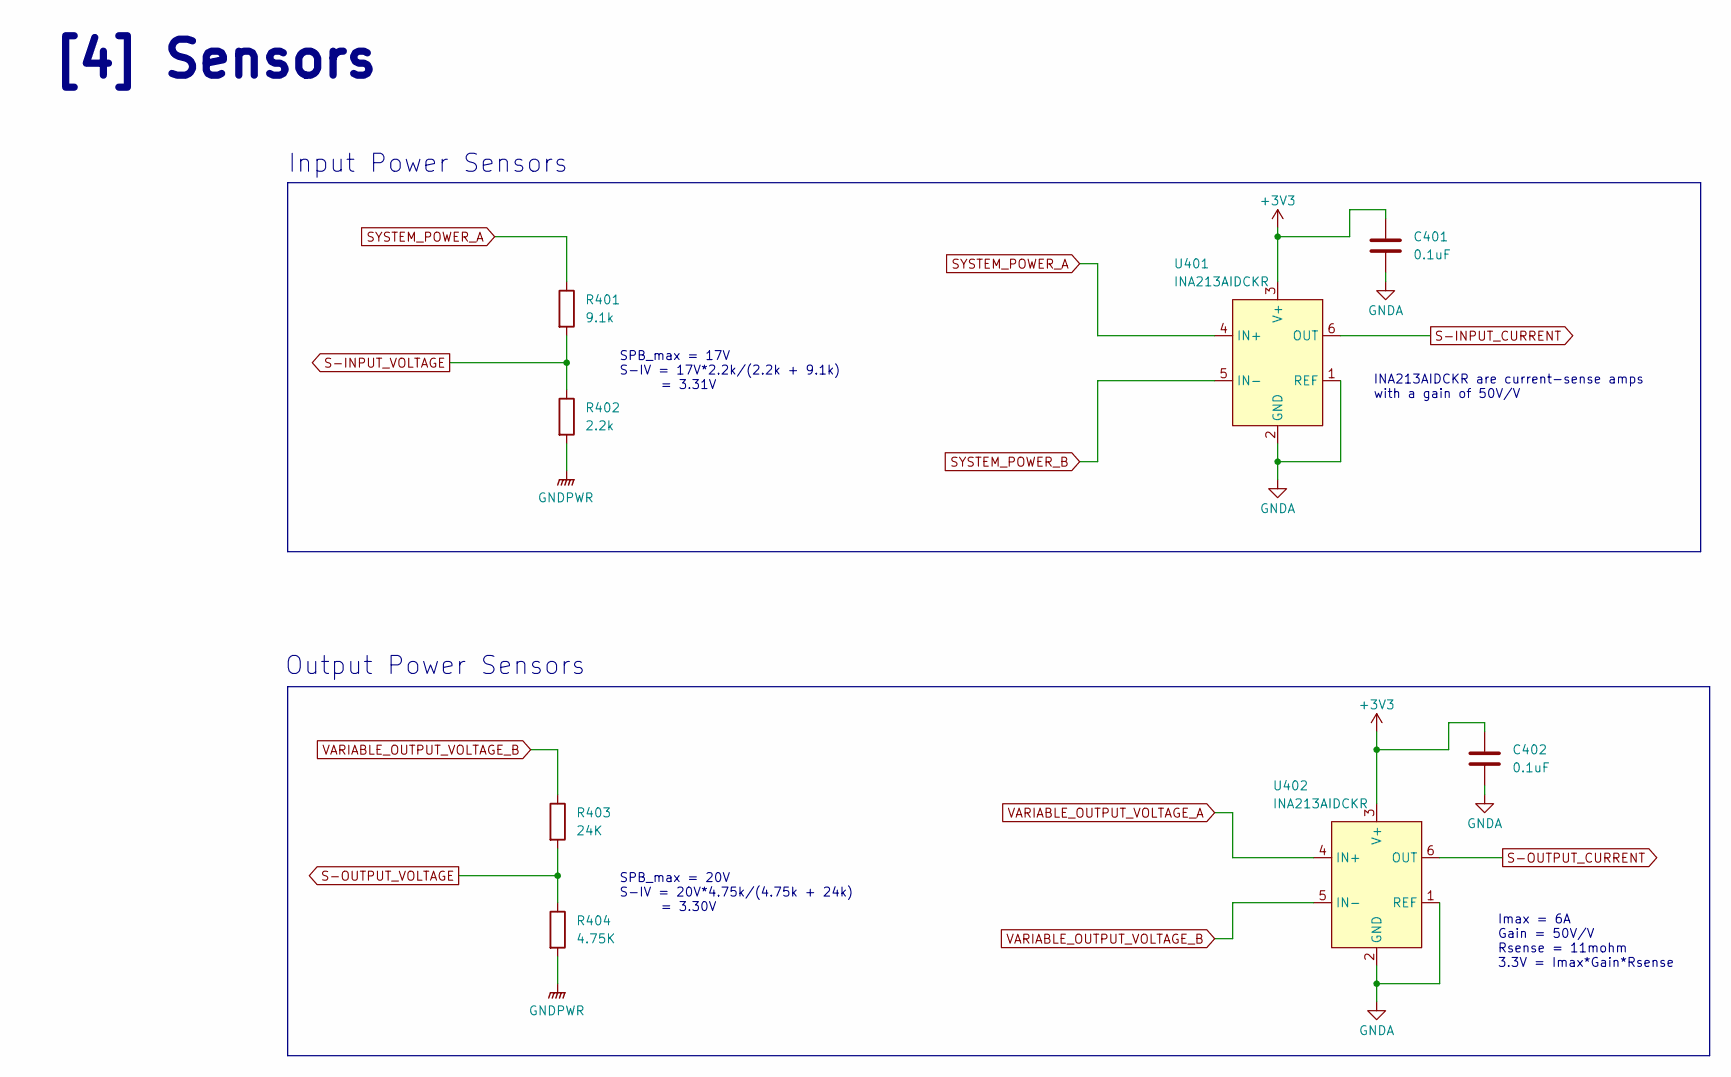
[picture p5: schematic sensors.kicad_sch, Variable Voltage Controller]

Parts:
C401, C402: 0.1uF; C_0402_1005Metric; Manufacturer Part # CL05B104KA5NNNC; lcsc C155422
R401: 9.1k; R_0603_1608Metric; Manufacturer Part # 0603WAF9101T5E; lcsc C23260
R402: 2.2k; R_0603_1608Metric; Manufacturer Part # 0603WAF2201T5E; lcsc C4190
R403: 24K; R_0402_1005Metric; Manufacturer Part # ERJ2RKF2402X; lcsc C409902
R404: 4.75K; R_0402_1005Metric; Manufacturer Part # 0402WGF4751TCE; lcsc C25901
U401, U402: INA213AIDCKR; SOT-363_SC-70-6; Manufacturer Part # INA213AIDCKR; lcsc C129346

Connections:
+3V3: C401.1, C402.1, U401.3 (V+), U402.3 (V+); also elsewhere on the board
GNDA: C401.2, C402.2, U401.1 (REF), U401.2 (GND), U402.1 (REF), U402.2 (GND); also elsewhere on the board
GNDPWR: R402.2, R404.2; also elsewhere on the board
S-INPUT_CURRENT: U401.6 (OUT); also elsewhere on the board
S-INPUT_VOLTAGE: R401.2, R402.1; also elsewhere on the board
S-OUTPUT_CURRENT: U402.6 (OUT); also elsewhere on the board
S-OUTPUT_VOLTAGE: R403.2, R404.1; also elsewhere on the board
SYSTEM_POWER_A: R401.1, U401.4 (IN+); also elsewhere on the board
SYSTEM_POWER_B: U401.5 (IN-); also elsewhere on the board
VARIABLE_OUTPUT_VOLTAGE_A: U402.4 (IN+); also elsewhere on the board
VARIABLE_OUTPUT_VOLTAGE_B: R403.1, U402.5 (IN-); also elsewhere on the board

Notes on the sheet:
INA213AIDCKR are current-sense amps with a gain of 50V/V
Output Power Sensors
Imax = 6A Gain = 50V/V Rsense = 11mohm 3.3V = Imax*Gain*Rsense
SPB_max = 17V S-IV = 17V*2.2k/(2.2k + 9.1k) = 3.31V
[4] Sensors
Input Power Sensors
SPB_max = 20V S-IV = 20V*4.75k/(4.75k + 24k) = 3.30V

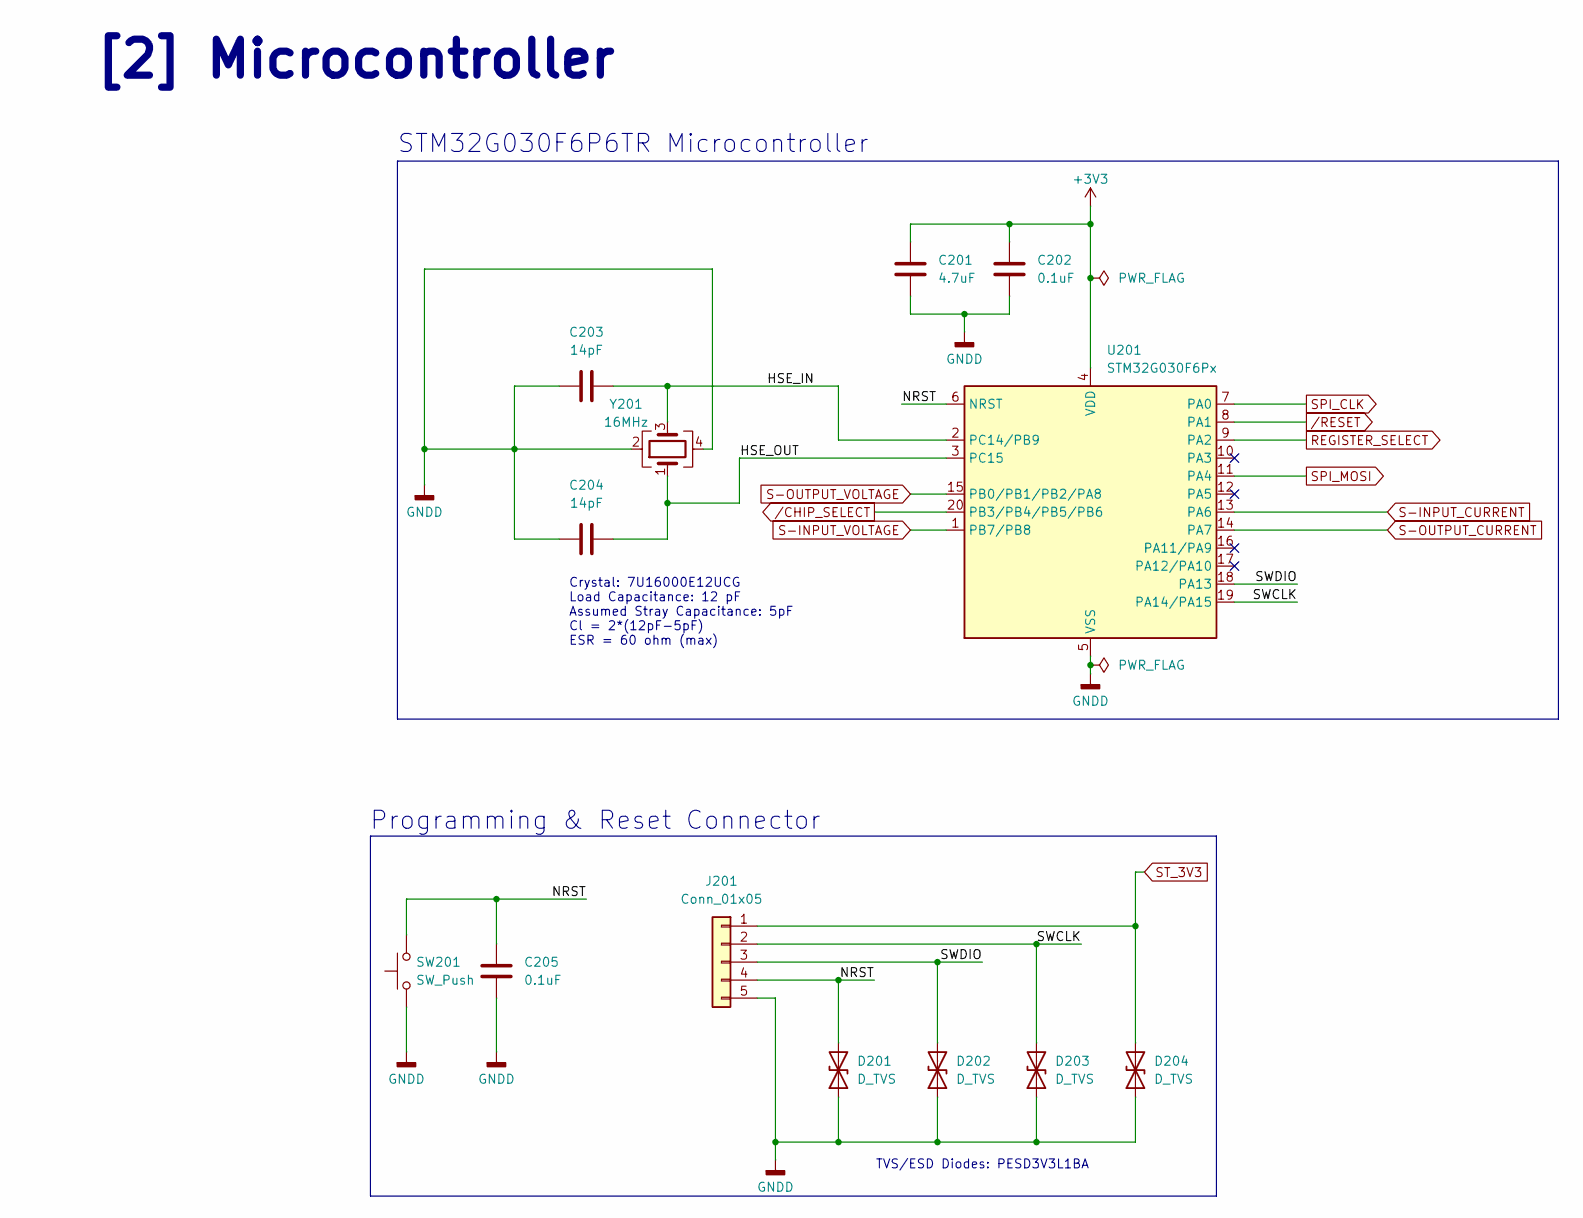
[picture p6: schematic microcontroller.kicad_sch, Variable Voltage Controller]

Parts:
C201: 4.7uF; C_0402_1005Metric; Manufacturer Part # CL05A475MP5NRNC; lcsc C23733
C202, C205: 0.1uF; C_0402_1005Metric; Manufacturer Part # CL05B104KA5NNNC; lcsc C155422
C203, C204: 14pF; C_0402_1005Metric; Manufacturer Part # 0402N140J500CT; lcsc C458857
D201, D202, D203, D204: D_TVS; D_SOD-323; Manufacturer Part # PESD3V3L1BA,115; lcsc C51450
J201: Conn_01x05; PinHeader_1x05_P2.54mm_Vertical; Manufacturer Part # PPTC051LFBN-RC
SW201: SW_Push; SW_Tactile_SPST_NO_Straight_CK_PTS636Sx25SMTRLFS; Manufacturer Part # PTS636SKG25SMTR LFS
U201: STM32G030F6Px; TSSOP-20_4.4x6.5mm_P0.65mm; Manufacturer Part # STM32G030F6P6; lcsc C724040
Y201: 16MHz; Crystal_SMD_3225-4Pin_3.2x2.5mm; Manufacturer Part # 7U16000E12UCG; lcsc C251610

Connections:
+3V3: C201.1, C202.1, U201.4 (VDD); also elsewhere on the board
/[2] Microcontroller/HSE_IN: C203.2, U201.2 (PC14/PB9), Y201.3
/[2] Microcontroller/HSE_OUT: C204.2, U201.3 (PC15), Y201.1
/[2] Microcontroller/NRST: C205.1, D201.2 (A2), J201.4, SW201.2, U201.6 (NRST)
/[2] Microcontroller/SWCLK: D203.2 (A2), J201.2, U201.19 (PA14/PA15)
/[2] Microcontroller/SWDIO: D202.2 (A2), J201.3, U201.18 (PA13)
GNDD: C201.2, C202.2, C203.1, C204.1, C205.2, D201.1 (A1), D202.1 (A1), D203.1 (A1), D204.1 (A1), J201.5, SW201.1, U201.5 (VSS), Y201.2, Y201.4; also elsewhere on the board
REGISTER_SELECT: U201.9 (PA2); also elsewhere on the board
S-INPUT_CURRENT: U201.13 (PA6); also elsewhere on the board
S-INPUT_VOLTAGE: U201.1 (PB7/PB8); also elsewhere on the board
S-OUTPUT_CURRENT: U201.14 (PA7); also elsewhere on the board
S-OUTPUT_VOLTAGE: U201.15 (PB0/PB1/PB2/PA8); also elsewhere on the board
SPI_CLK: U201.7 (PA0); also elsewhere on the board
SPI_MOSI: U201.11 (PA4); also elsewhere on the board
ST_3V3: D204.2 (A2), J201.1; also elsewhere on the board
/CHIP_SELECT: U201.20 (PB3/PB4/PB5/PB6); also elsewhere on the board
/RESET: U201.8 (PA1); also elsewhere on the board

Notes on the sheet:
TVS/ESD Diodes: PESD3V3L1BA
Programming & Reset Connector
Crystal: 7U16000E12UCG Load Capacitance: 12 pF Assumed Stray Capacitance: 5pF Cl = 2*(12pF-5pF) ESR = 60 ohm (max)
STM32G030F6P6TR Microcontroller
[2] Microcontroller

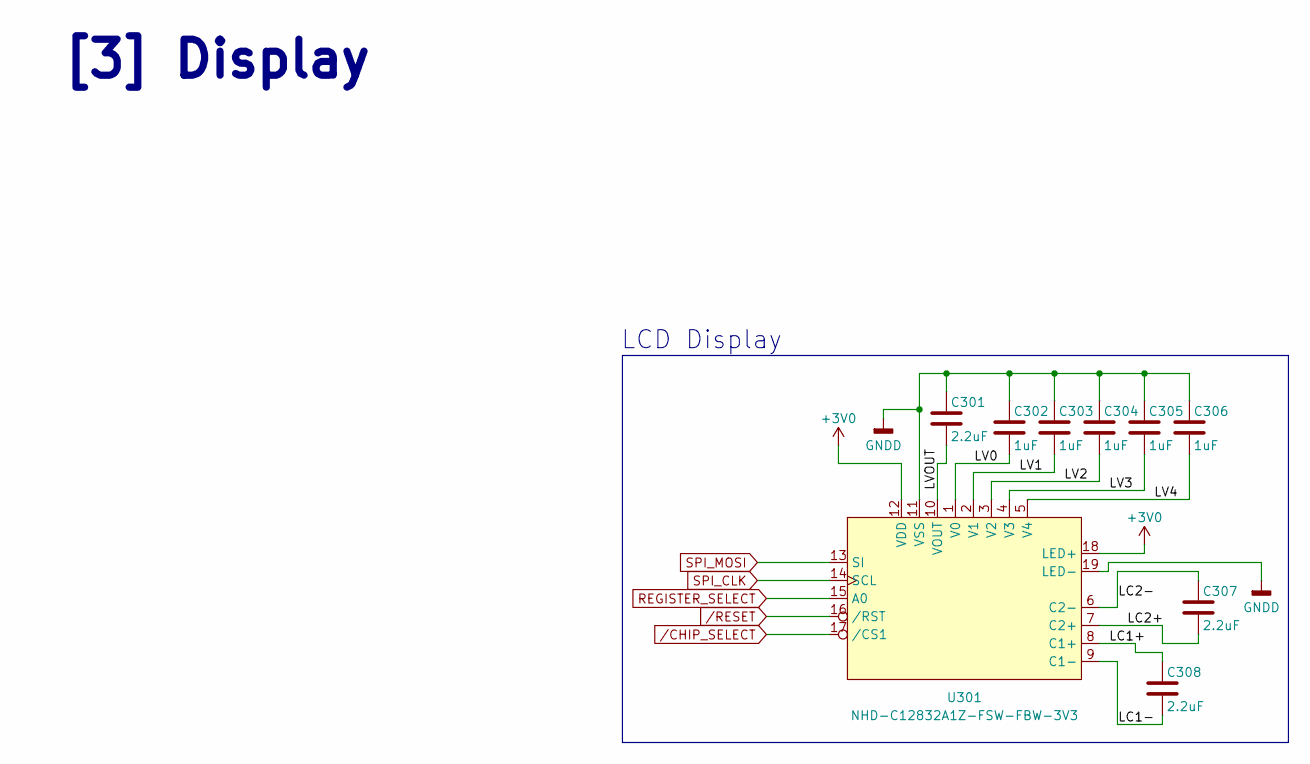
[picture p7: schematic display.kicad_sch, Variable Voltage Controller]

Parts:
C301, C307, C308: 2.2uF; C_0402_1005Metric; Manufacturer Part # CL05A225MQ5NSNC; lcsc C12530
C302, C303, C304, C305, C306: 1uF; C_0402_1005Metric; Manufacturer Part # CL05A105KA5NQNC; lcsc C52923
U301: NHD-C12832A1Z-FSW-FBW-3V3; NHD-C12832A1Z-FSRGB; Manufacturer Part # NHD-C12832A1Z-FSW-FBW-3V3

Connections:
+3V0: U301.12 (VDD), U301.18 (LED+); also elsewhere on the board
/[3] Display/LC1+: C308.1, U301.8 (C1+)
/[3] Display/LC1-: C308.2, U301.9 (C1-)
/[3] Display/LC2+: C307.2, U301.7 (C2+)
/[3] Display/LC2-: C307.1, U301.6 (C2-)
/[3] Display/LV0: C302.2, U301.1 (V0)
/[3] Display/LV1: C303.2, U301.2 (V1)
/[3] Display/LV2: C304.2, U301.3 (V2)
/[3] Display/LV3: C305.2, U301.4 (V3)
/[3] Display/LV4: C306.2, U301.5 (V4)
/[3] Display/LVOUT: C301.2, U301.10 (VOUT)
GNDD: C301.1, C302.1, C303.1, C304.1, C305.1, C306.1, U301.11 (VSS), U301.19 (LED-); also elsewhere on the board
REGISTER_SELECT: U301.15 (A0); also elsewhere on the board
SPI_CLK: U301.14 (SCL); also elsewhere on the board
SPI_MOSI: U301.13 (SI); also elsewhere on the board
/CHIP_SELECT: U301.17 (/CS1); also elsewhere on the board
/RESET: U301.16 (/RST); also elsewhere on the board

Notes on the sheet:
LCD Display
[3] Display

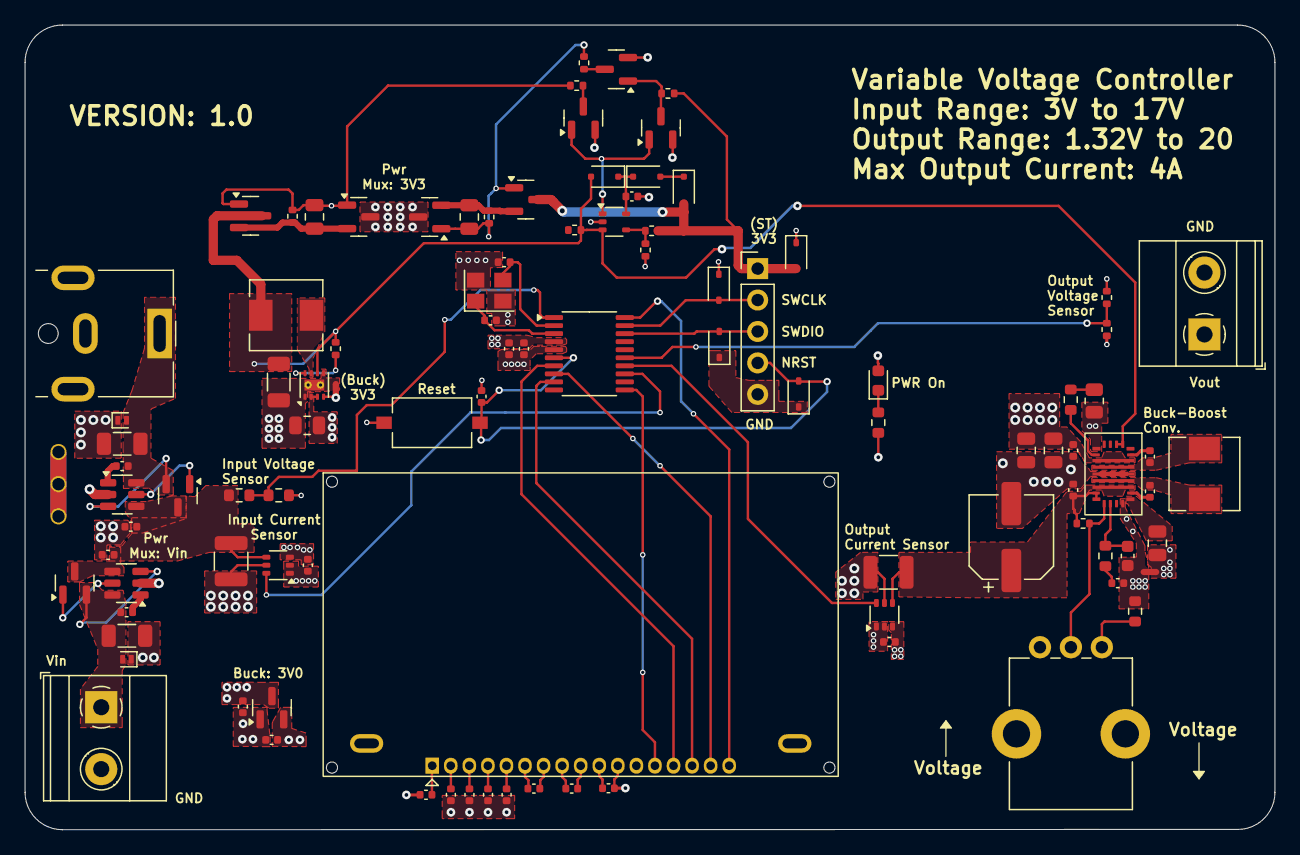
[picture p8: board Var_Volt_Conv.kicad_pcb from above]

Board: 6 copper layers, 101.0 x 65.0 mm, 100 parts (0 on the bottom side), 66 nets.

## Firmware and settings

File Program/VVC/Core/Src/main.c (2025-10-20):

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
/* Includes ------------------------------------------------------------------*/
#include "main.h"

/* USER CODE BEGIN Includes */
#include <stdio.h>
#include <string.h>
#include "fonts.h"
#include "NHD_lcd.h"
#include "float2string.h"
/* USER CODE END Includes */

/* USER CODE BEGIN PD */
#define NUM_SENSORS 4
/* USER CODE END PD */

ADC_HandleTypeDef hadc1;

SPI_HandleTypeDef hspi2;

/* USER CODE BEGIN PV */
typedef enum sensor_val {v_input, v_output, i_input, i_output} Sensor_Value;
static const uint16_t g_adc_res = 65535;// ADC resolution = 2^16-1 /*4095;*/	//ADC resolution = 2^12-1
static const uint8_t g_vi_scale = 17; //largest allowable input voltage
static const uint8_t g_vo_scale = 20; //largest allowable output voltage
static const float g_current_scale = 3.3/(50*0.011f); //Amp gain * Rsense
static const float g_scales[NUM_SENSORS] = {g_vi_scale, g_vo_scale, g_current_scale, g_current_scale};
static uint16_t g_adc_buffer[NUM_SENSORS];

static const char g_vi_header[] = "Input Voltage: ";
static const char g_vo_header[] = "Output Voltage: ";
static const char g_ii_header[] = "Input Current: ";
static const char g_io_header[] = "Output Current: ";
static const char * g_unit_symbols[] = {" V", " A"};
static const uint8_t g_header_len[NUM_SENSORS] = {strlen(g_vi_header), strlen(g_vo_header),
    strlen(g_ii_header), strlen(g_io_header)};
#define MAX_NUM_LEN 10
static char g_num_text[MAX_NUM_LEN];
static char g_dest_text[NUM_COLS];
static const char * g_headers[NUM_SENSORS] = {g_vi_header, g_vo_header, g_ii_header, g_io_header};
//ERROR LOGGING
#define LOG_FLASH_START 0X0800F800U
#define MAX_LOG_NUM 256
#define LOG_FLASH_PAGE_NUM 31U
typedef struct log_struct{
  char b0;  //'I'
  uint8_t err_count;
  char source; // 'N' or 'P'
  uint8_t b1; //'T'
  uint8_t err_type;
  char b2;  //'L'
  uint16_t line_num;
} log_struct_t;
typedef enum process
  {init = 'N' /*Initialization function*/, print = 'P' /*Print to LCD display function*/
 } Process;

/* USER CODE END PV */

void SystemClock_Config(void);
static void MX_GPIO_Init(void);
static void MX_ADC1_Init(void);
static void MX_SPI2_Init(void);
/* USER CODE BEGIN PFP */
static NHD_LCDstatus_t print_power_value(NHD_LCD_Handle_t* lcd_handle, uint8_t index);
static void log_error(uint16_t line, char source, NHD_LCDstatus_t err);


/* USER CODE END PFP */

/**
  * @brief  The application entry point.
  * @retval int
  */
int main(void)
{

  /* USER CODE BEGIN 1 */
  //initialise_monitor_handles();
  /* USER CODE END 1 */

  /* MCU Configuration--------------------------------------------------------*/

  /* Reset of all peripherals, Initializes the Flash interface and the Systick. */
  HAL_Init();

  /* Configure the system clock */
  SystemClock_Config();

  /* Initialize all configured peripherals */
  MX_GPIO_Init();
  MX_ADC1_Init();
  MX_SPI2_Init();
  /* USER CODE BEGIN 2 */

  // Configure NHD_LCD handle
  NHD_LCD_Handle_t lcd_handle = {
      .hspi = &hspi2,
      .cs_port = _CS_GPIO_Port,
      .cs_pin = _CS_Pin,
      .op_port = A0_GPIO_Port,
      .op_pin = A0_Pin,
      .reset_port = _RST_GPIO_Port,
      .reset_pin = _RST_Pin,
  };


  NHD_LCD_Reset_Screen(&lcd_handle);//Doesn't call SPI-related methods

  NHD_LCDstatus_t err_code = NHD_SPI_OK;

  err_code = NHD_LCD_Init_Screen(&lcd_handle);
  if (err_code != NHD_SPI_OK)
  {
    log_error(__LINE__, (char)init, err_code);
  }
  err_code = NHD_LCD_Clear_Screen(&lcd_handle);
  if (err_code != NHD_SPI_OK)
  {
    log_error(__LINE__, (char)init, err_code);
  }
  err_code = NHD_LCD_Write_Data(&lcd_handle, SET_SRT_ROW); // To first line
  if (err_code != NHD_SPI_OK)
  {
    log_error(__LINE__, (char)init, err_code);
  }


  /* USER CODE END 2 */

  /* Infinite loop */
  /* USER CODE BEGIN WHILE */
  while (1)
  {
	  //Get voltage and current values from ADC
	  for (int i = 0; i < NUM_SENSORS; i++)
	  {
		  HAL_ADC_Start(&hadc1);
		  HAL_ADC_PollForConversion(&hadc1, 1);
		  g_adc_buffer[i] = HAL_ADC_GetValue(&hadc1);

	  }//Now the buffer contains all 4 values.
	  HAL_ADC_Stop(&hadc1); //Needed in for OVERSAMPLING MODE to work

	  //Send input voltage, output voltage, input current, output current to the LCD screen
	  err_code = print_power_value(&lcd_handle, v_input);
	  if (err_code != NHD_SPI_OK)
	  {
	    log_error(__LINE__, (char)print, err_code);
	  }
	  err_code = print_power_value(&lcd_handle, v_output);
	  if (err_code != NHD_SPI_OK)
	  {
	    log_error(__LINE__, (char)print, err_code);
	  }
	  err_code = print_power_value(&lcd_handle, i_input);
	  if (err_code != NHD_SPI_OK)
	  {
	    log_error(__LINE__, (char)print, err_code);
	  }
	  err_code = print_power_value(&lcd_handle, i_output);
	  if (err_code != NHD_SPI_OK)
	  {
	    log_error(__LINE__, (char)print, err_code);
	  }
	  //delay for 100ms
	  HAL_Delay(100);
    /* USER CODE END WHILE */

    /* USER CODE BEGIN 3 */
  }
  /* USER CODE END 3 */
}

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
/* USER CODE BEGIN 4 */


/**
 * @brief This function prints the value of the voltage/current on the LCD screen
 *
 * @param index: The character row that the value would be displayed on
 * @retval NHD_LCD status
 */
static NHD_LCDstatus_t print_power_value(NHD_LCD_Handle_t* lcd_handle, uint8_t index)
{
	// Set the number digits after the decimal point, and identify if it a current value or voltage value
	uint8_t decimals = 0;
	uint8_t symbol_index;
	if (index == v_input || index == v_output)
	{
		decimals = 1;
		symbol_index = 0;
	}
	else // if(index == i_input || i_output)
	{
		decimals = 2;
		symbol_index = 1;
	}

	// Convert the ADC value from an integer->float->string
	ftoa((float)g_adc_buffer[index]*g_scales[index]/g_adc_res, g_num_text, decimals);

	// Concatenate the header string, value string and symbol string
	uint8_t num_text_len = strlen(g_num_text);
	uint8_t symbol_len = strlen(g_unit_symbols[symbol_index]);
	uint8_t total_len = g_header_len[index] + num_text_len + symbol_len;

	if (sizeof(g_dest_text) - 1 > total_len) //checks there is enough space in the buffer for the combined text
	{
	  memcpy(g_dest_text, g_headers[index], g_header_len[index]);
		memcpy(g_dest_text + g_header_len[index], g_num_text, num_text_len);
		memcpy(g_dest_text + g_header_len[index] + num_text_len,
		    g_unit_symbols[symbol_index], symbol_len + 1); // "+ 1" to add '\0'
	}
	else
	{
	  NHD_LCDstatus_t err_code = NHD_SPI_OK;
	  if ((err_code = NHD_LCD_Print_Data(lcd_handle, "Error: string was too long", index)) != NHD_SPI_OK)
	    return err_code;
	}

	// Print string to the LCD string
	NHD_LCDstatus_t err_code = NHD_SPI_OK;
	if ((err_code = NHD_LCD_Print_Data(lcd_handle, g_dest_text, index)) != NHD_SPI_OK)
		return err_code;

	return err_code;
}

void log_error(uint16_t line, char source, NHD_LCDstatus_t err)
{
  __disable_irq();
  // Populate Error Log values
  log_struct_t log;
  log.b0 = 'I';
  log.b1 = 'T';
  log.b2 = 'L';
  log.line_num = line;
  log.source = source;
  log.err_type = err;

  // Unlock the Flash
  if (HAL_FLASH_Unlock() != HAL_OK)
  {
    //Flash Unlocked Failed
    Error_Handler();
  }

  log_struct_t *plog = (log_struct_t*)LOG_FLASH_START;
  uint32_t addr;
  uint64_t data;
  uint8_t data_saved = 0;
  HAL_StatusTypeDef status;
  for(uint8_t i = 0; i < MAX_LOG_NUM; i++) //Search for first available index in page to save error log
  {
    if(plog->b0 != 'I')
    { //
      log.err_count = i;
      data =  *(uint64_t*)&log;
      addr = (uint32_t)plog;
      status = HAL_FLASH_Program(FLASH_TYPEPROGRAM_DOUBLEWORD, addr, data);
      if(status != HAL_OK)
      {
        //Logging Error into Flash Failed
        Error_Handler();
      }
      data_saved = 1;
      break;
    }
    plog++;
  }

  if(!data_saved) //Flash page is full, must be cleared before adding a new entry
  {
    FLASH_EraseInitTypeDef erase_config;
    erase_config.TypeErase = FLASH_TYPEERASE_PAGES;
    erase_config.Banks = FLASH_BANK_1;
    erase_config.Page = LOG_FLASH_PAGE_NUM;
    erase_config.NbPages = 1;
    uint32_t page_error;
    status = HAL_FLASHEx_Erase(&erase_config, &page_error);
    if(status != HAL_OK)
    {
      //Logging Error into Flash Failed
      Error_Handler();
    }

    log.err_count = 0;
    data =  *(uint64_t*)&log;
    addr = (uint32_t)LOG_FLASH_START;
    status = HAL_FLASH_Program(FLASH_TYPEPROGRAM_DOUBLEWORD, addr, data);
    if(status != HAL_OK)
    {
      //Logging Error into Flash Failed
      Error_Handler();
    }
    data_saved = 1;
  }
  HAL_FLASH_Lock();
  Error_Handler();
}


/* USER CODE END 4 */
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


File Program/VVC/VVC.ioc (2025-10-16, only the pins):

Mcu.UserName=STM32G030F6Px
PA0.Signal=SPI2_SCK
PA1.GPIO_Label=_RST
PA1.Signal=GPIO_Output
PA13.Signal=SYS_SWDIO
PA14-BOOT0.Signal=SYS_SWCLK
PA2.GPIO_Label=A0
PA2.Signal=GPIO_Output
PA4.Signal=SPI2_MOSI
PA6.GPIO_Label=S-Input Current
PA6.Signal=ADC1_IN6
PA7.GPIO_Label=S-Output Current
PA7.Signal=ADC1_IN7
PB0.GPIO_Label=S-Output Voltage
PB0.Signal=ADC1_IN8
PB3.GPIO_Label=_CS
PB3.Signal=GPIO_Output
PB7.GPIO_Label=S-Input Voltage
PB7.Signal=ADC1_IN11

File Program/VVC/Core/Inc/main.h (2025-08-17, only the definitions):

#define S_Input_Voltage_Pin GPIO_PIN_7
#define S_Input_Voltage_GPIO_Port GPIOB
#define _RST_Pin GPIO_PIN_1
#define _RST_GPIO_Port GPIOA
#define A0_Pin GPIO_PIN_2
#define A0_GPIO_Port GPIOA
#define S_Input_Current_Pin GPIO_PIN_6
#define S_Input_Current_GPIO_Port GPIOA
#define S_Output_Current_Pin GPIO_PIN_7
#define S_Output_Current_GPIO_Port GPIOA
#define S_Output_Voltage_Pin GPIO_PIN_0
#define S_Output_Voltage_GPIO_Port GPIOB
#define _CS_Pin GPIO_PIN_3
#define _CS_GPIO_Port GPIOB

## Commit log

2025-01-03 Add microcontroller schematic - STM32G030F6P6
    [Var_Volt_Conv.kicad_pcb, Var_Volt_Conv.kicad_sch, microcontroller.kicad_sch]
2025-01-03 Changed all labels to flags, except for NRST, SWDIO and SWCLK
    [microcontroller.kicad_sch]
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2025-01-06 Deleted Full_Power_Selector tests, using the switch didn't help provide new insights
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2025-01-11 Add 3.3V buck Converter TPS61272DSGT
    [Power.kicad_sch, Var_Volt_Conv.kicad_sch, microcontroller.kicad_sch]
2025-01-11 Add reverse voltage protection circuit
2025-01-11 Added 'Ideal Diode OR controller' that wil, switch between terminal block and jack power depending on which voltage is higher
    [Power.kicad_sch]
2025-01-11 Add prioritized Power multiplecer for 3V3
    [Power.kicad_sch]
2025-01-12 Corrected Buck and ST-Link power comparator circuit
    [Power.kicad_sch]
2025-01-13 Add TPS552872RYQR library, symbol and to the power schematic
    [Power.kicad_sch]
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2025-01-14 Add _CS, _RST and A0 (active low chip select, active low reset, and register select for LCD display to the microcontroller pin plan
    [Variable_Voltage_Controller.ioc]
2025-01-14 Tidied up microcontoller schematic
    [Power.kicad_sch, Var_Volt_Conv.kicad_sch, display.kicad_sch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]
2025-01-15 Add Current-sense amps library, INA215-75V/V gain and INA213-50V/V gain symbols
    [Var_Volt_Conv.kicad_sch, display.kicad_sch, sensors.kicad_sch]
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2025-01-16 Add bounding boxes and title/labels to all the sub-circuits
    [Power.kicad_sch, display.kicad_sch, microcontroller.kicad_sch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]
2025-01-16 Add Excel file of compensation calculations - converter can only output 5A in boost mode if Vin=Vout=3V
    [Buck-Boost_Compensation_Calculations.xlsx]
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2025-01-16 Added compensation circuitry values - Finished first draft of the entire schematic
    [Power.kicad_sch]
2025-01-17 Rename power nets and integrated current sensing into power circuit
    [Power.kicad_sch, microcontroller.kicad_sch, sensors.kicad_sch]
2025-01-17 Add Application notes to power schematic
    [Power.kicad_sch]
2025-01-17 Added System Power Multiplexer to calculations folder, explained the Power multiplexer
    [Buck-Boost_Compensation_Calculations.xlsx]
2025-01-20 Simulated LM4700-Q1 ideal voltage controller with 1, 5, 50 and 5k ohms, with the CSD18540Q5B nmos (this was used in the original file), work correctly, V_AK was always 20mV
2025-01-20 Replaced Ideal OR transistors with IRFML8244TRPBF
    [Power.kicad_sch]
2025-01-20 Tested LM74700 with a transistor that posses on on resistance of about 160mA, at 5A the voltage drop was around 800mV, VGS was about 12V, didn't seem stable
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2025-01-20 Sourced TVS diodes for input system power
    [Power.kicad_sch]
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2025-01-23 Minor changes to auxilliary components of System Power sub-cictui
    [Power.kicad_sch]
2025-01-23 Made notes on 3V3 priority power multiplexer circuit and minor corrections
    [Power.kicad_sch]
2025-01-24 Done reviewing Buck-Boost converter circuit, made minor corrections
    [Power.kicad_sch]
2025-01-24 LCD screen needs a nominal supply voltage of 3V, added a 3V LDOto the power circuitry, the LDO is powered by the buck converter
    [Power.kicad_sch, display.kicad_sch]
2025-01-25 Finalized current sensing circuit values
    [Buck-Boost_Compensation_Calculations.xlsx, Current_Sense_Amps_Options.xlsx, Power.kicad_sch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]
2025-01-25 Finished verifying and making notes on current sensors
    [Current_Sense_Amps_Options.xlsx]
2025-01-26 Added microcontroller notes, and power indicator LED
    [Power.kicad_sch, microcontroller.kicad_sch]
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2025-01-26 Fixed ERC issues
    [Power.kicad_sch, display.kicad_sch, microcontroller.kicad_sch]
2025-01-26 Add footprints and correct LCD pin numbering
    [Power.kicad_sch, display.kicad_sch, microcontroller.kicad_sch]
2025-01-26 Add filter caps to current sensors
    [display.kicad_sch, sensors.kicad_sch]
2025-01-26 Add footprints for all capacitors, and record cap part names
    [Passives_BOM.xlsx, Power.kicad_sch, display.kicad_sch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]
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2025-01-26 Added footprints to all components except the connectors and buck-boost converter
    [Passives_BOM.xlsx, Power.kicad_sch, microcontroller.kicad_sch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]
2025-01-26 Assign footprints to all footprints except the buck-boost converter
    [Passives_BOM.xlsx, Power.kicad_sch, microcontroller.kicad_sch]
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2025-01-27 Connected FB pin of 3.3V buck converter to ground
    [Power.kicad_sch]
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2025-01-29 Routed signal traces and made power pours for microcontroller and display, also changed 4.7, 1uF and 2.2uF caps to 0402
    [Passives_BOM.xlsx, Power.kicad_sch, Var_Volt_Conv.kicad_pcb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]
2025-01-30 Routed Input system power circuitry, and named the LM74700 gate connection nets
    [Power.kicad_sch, Var_Volt_Conv.kicad_pcb]
2025-01-30 Finished tracing priority 3.3V power multiplexer, changed terminal block footprints to 5.00mm pitch
    [Power.kicad_sch, Var_Volt_Conv.kicad_pcb]
2025-01-30 Finished traces buck-boost converter, add 3D model of the converter as well
    [RYQ0021A.stp, Var_Volt_Conv.kicad_pcb]
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2025-01-30 Rounded PCB corners and add remaining 3D models
    [NHD-C12832A1Z.STEP, PTV09A-4225F-B104.step, Var_Volt_Conv.kicad_pcb]
2025-01-30 Corrected LCD screen footprint
    [Var_Volt_Conv.kicad_pcb]
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2025-01-30 Finish organizing sub-circuits, and input voltage sensor sensing System_voltage_input_A instead of B
    [Var_Volt_Conv.kicad_pcb, sensors.kicad_sch]
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2025-02-01 Finish tracing all non-power related nets, changed uC pins for Chip Select, Register Select, Reset, Output Voltage sensing, input current sensing and output voltage sensing
    [Var_Volt_Conv.kicad_pcb, microcontroller.kicad_sch]
2025-02-02 connected all traces, poured all copper pours, passed ERC
    [Var_Volt_Conv.kicad_pcb]
2025-02-02 Updated power and analog ground connections of the buck converter
    [Power.kicad_sch, Var_Volt_Conv.kicad_pcb]
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2025-05-11 Change difference amplifieres in sensor section form 75V/V to 50V/V
    [Var_Volt_Conv.kicad_pcb, sensors.kicad_sch]
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2025-07-08 Updated schematic, C121, R112 and SW201 now use components that are still in stock on JLCPCB
    [BOM-Var_Volt_Conv.csv, DigiKey BOM Focused.xlsx, DigiKey BOM.csv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]
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2025-07-09 Downloaded doc from JLCPCB after going through order process, lots of extended components increases cost of PCBA, replaced a few with Basic components
    [BOM-Var_Volt_Conv-JLCPCB Assembly Order.xls]
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2025-07-10 Will source switch from Digikey, decided what to source from digikey and what to source from JLCPCB
    [BOM-Var_Volt_Conv.csv, BOM.csv, BOM_Final.csv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]
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2025-07-15 Change layer order, formerly SGN-GNDPWR-VCC-GNDA-GNDD-SGN, it is now SGN-GND-VCC-GNDPWR-GNDA-SGN
    [Var_Volt_Conv.kicad_pcb]
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2025-08-04 Changed Q104 to Q107 to basic component AO3401A, and changed R104 and R108 to 50k
    [Power.kicad_sch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]
2025-08-17 Corrected Pic assigments in MX file (switched Chip select and reset pins), began writing program for VVC - Can turn the LCD screen on and off
    [VVC.ioc, main.c, main.h]
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2025-08-17 Display Actual input & output voltage and current values, unfortunately there are variable steady state errors in all values
2025-08-17 Added HAL_ADCEx_Calibration_Start(&hadc1); greatly reduced steady state error
    [Power.kicad_sch]
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2025-08-18 add erase_trails function, if current output string is shorter than the output string that precedes it, then it fills those left over spaces with a ' ' character
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2025-08-29 Corrected voltage scaling: 3.3/(50x0.011)
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2025-09-26 Replaced tabs with 2 spaces to match stm32 code style
2025-10-07 Successfully reserved last page (2KB) of RAM for logging errors, also replaced pow(10, afterpoint) used in ftoa from the math.h library with different implementation -> resulted in a reduction of .te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
    [VVC.cfg]
2025-10-13 Added enum for processes that could lead to an error, also corrected sensor_val enum
    [main.c]
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2025-10-20 Improved NHD_LCD screen API, files (source, header and config) no longer dependent on main.h, created a handle for the display, all functions contain the handle in the parameter list, and user initia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
    [NHD_lcd.h, main.c]
2025-10-22 Added and updated comments to all functions in NHD driver, and replaced &SPI_HANDLE with NHD_handle->hspi in HAL_SPI_Transmit function, don't know how it was working before

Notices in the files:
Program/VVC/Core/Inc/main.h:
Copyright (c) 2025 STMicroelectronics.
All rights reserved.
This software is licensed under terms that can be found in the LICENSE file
